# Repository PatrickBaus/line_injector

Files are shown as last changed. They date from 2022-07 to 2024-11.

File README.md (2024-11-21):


# Line Injector
This repository contains the schematics and mechanical files for a line injector.

## Contents
- [Introduction](#introduction)
- [Bode Plot](#bode-plot)
- [PCB Design Files](#pcb-design-files)
- [Mechanical Design Files](#mechanical-design-files)
- [Related Repositories](#related-repositories)
- [Versioning](#versioning)
- [License](#license)

## Introduction
A line injector can be used to inject a ripple voltage into the supply line of a circuit. This can, for example, be used to measure the [power supply rejection ratio (PSRR)](https://en.wikipedia.org/wiki/Power_supply_rejection_ratio) of a regulator.

Key Features:
 * Bandwidth (-3 dB): 6 Hz - 35 MHz (into 50 Ω)
 * Passband transfer function is about 0.95 V/V (@ 5V) and 0.975 V/V (@ 15V)
 * Maximum input voltage: 50 V
 * Maximum current: 5 A
 * Remote sensing inputs to compensate for the voltage drop over the MOSFET

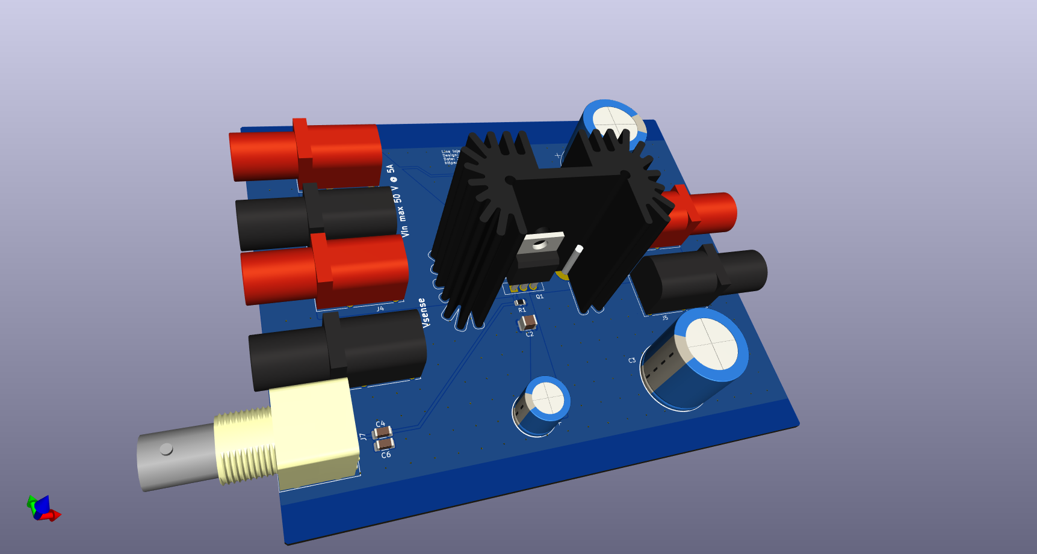
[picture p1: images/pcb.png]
Line injector pcb


The design was done using [KiCAD 8](https://www.kicad.org/).

## Bode Plot
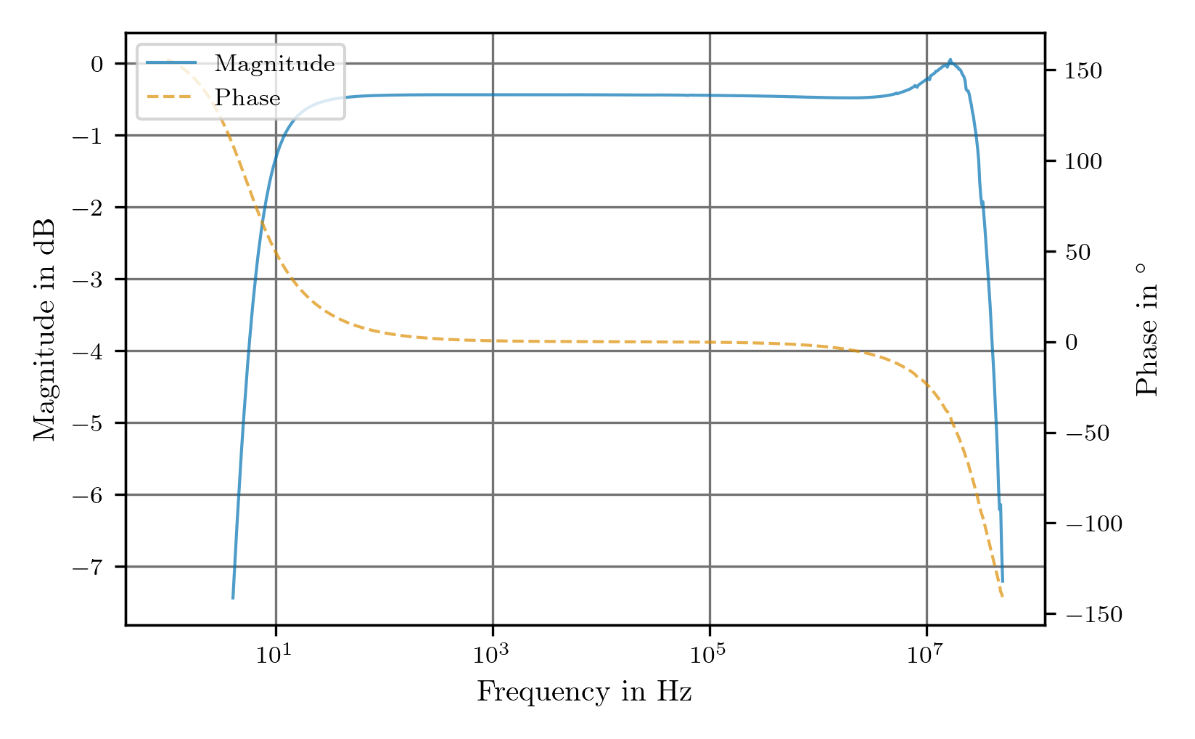
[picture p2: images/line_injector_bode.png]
Bode Plot


Additionally, a report from the Bode 100 VNA used to characterize the injector can be found [here](/supplemental/Line%20Injector_JFW.pdf).

Photos of the finished design
------------------------------

### Front
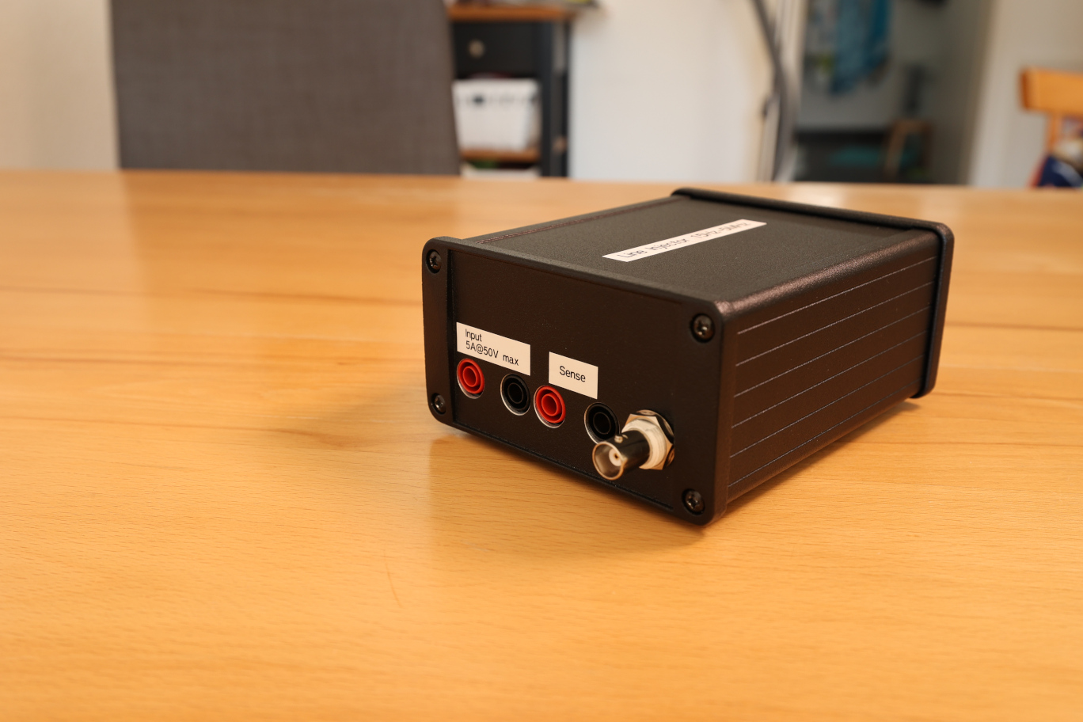
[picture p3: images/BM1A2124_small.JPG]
Line injector photo front


### Back
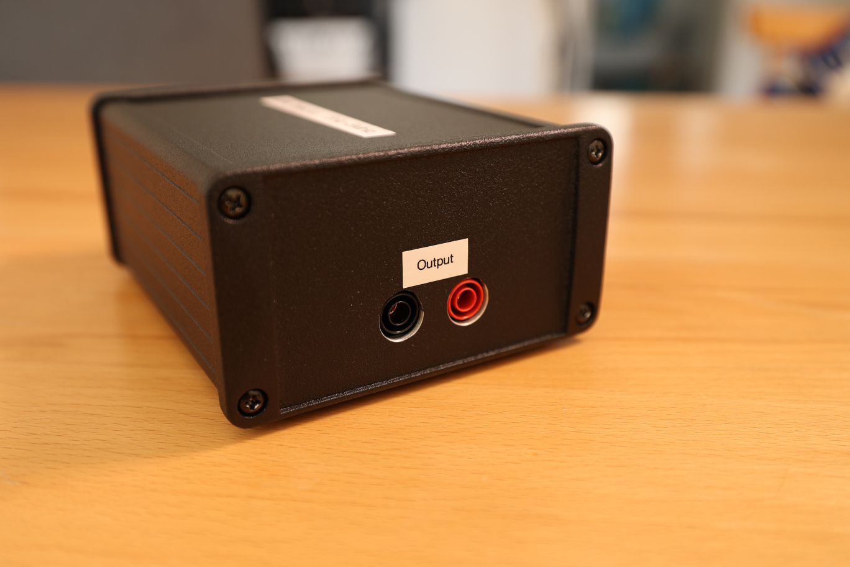
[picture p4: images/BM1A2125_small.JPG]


### PCB
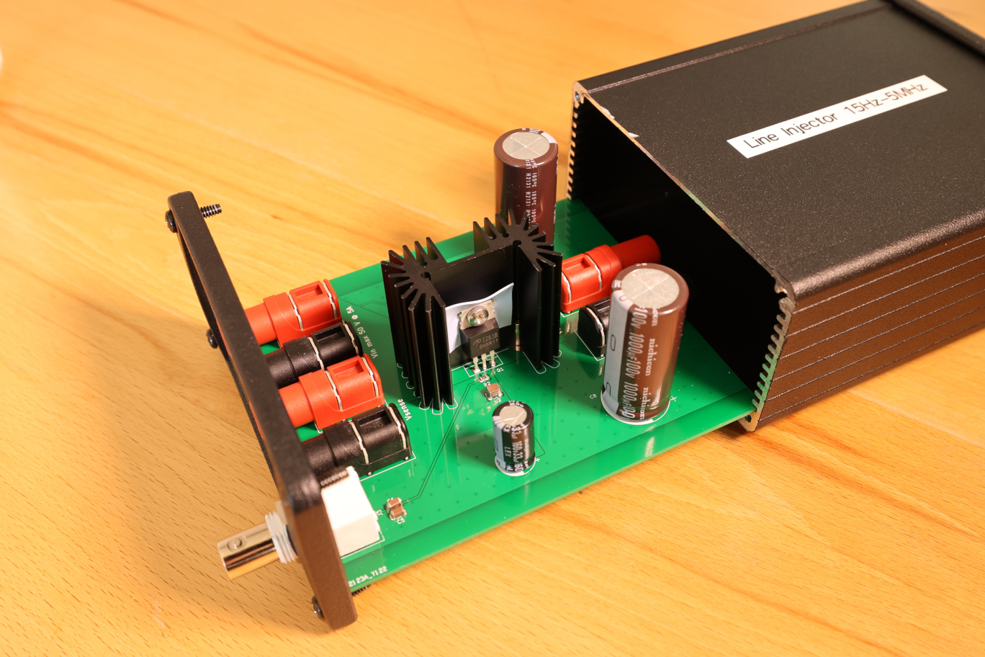
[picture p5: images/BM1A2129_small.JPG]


## PCB Design Files
The root folder contains the KiCAD files. The bill of materials can be found on the [releases](../../releases) page along with Gerber files for production.

## Mechanical Design Files
The PCB fits into a Hammond Manufacturing [1457N1201EBK](https://www.hammfg.com/electronics/small-case/extruded/1457-emi) case. Additionally a few drilled holes need to be drilled for the connectors.

## Related Repositories
See the following repositories for more information.

KiCAD footprints: https://github.com/PatrickBaus/footprints.pretty

## Versioning
I use [SemVer](http://semver.org/) for versioning. For the versions available, see the [tags](../../tags) available for this repository.

- MAJOR versions in this context mean a breaking change to the external interface of the hardware like different connectors or functions.
- MINOR versions contain changes to the hardware that only affect the inner workings of the circuit, but otherwise the performance is unaffected.
- PATCH versions do not affect the schematics or invalidate older bill of materials. These changes may include updated components (to replace obsolete parts for example), an updated silkscreen, or fixed typos.

## License
This work is released under the CERN-OHL-W
See [https://ohwr.org/cern_ohl_w_v2.pdf](https://ohwr.org/cern_ohl_w_v2.pdf) or the included LICENSE file for more information.

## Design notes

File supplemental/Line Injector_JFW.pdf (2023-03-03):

## Measurement: Transmission / Reflection

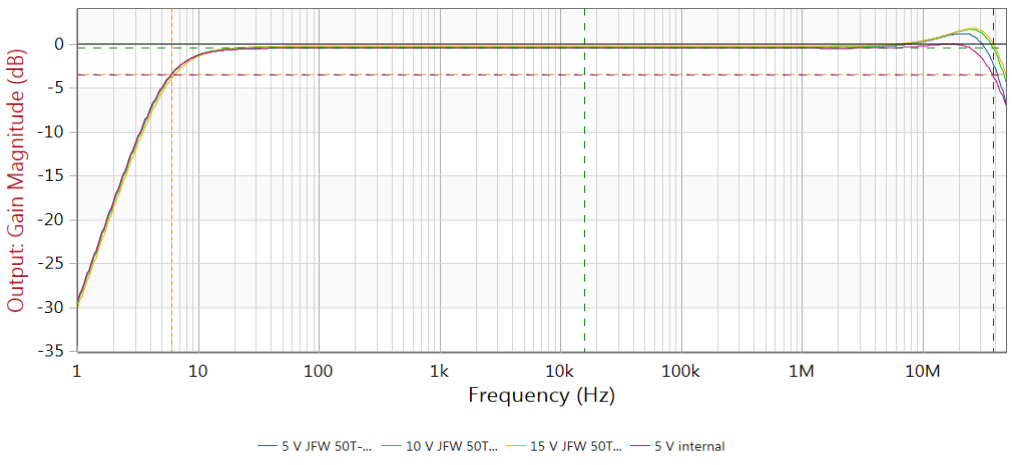
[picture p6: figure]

27.07.2022, 12:16 | Line Injector_JFW.pdf | Page 1/1
Cursor 1 | Cursor 2 | Cursor 3
Frequency | 15,828 kHz | 6,029 Hz | 38,902 MHz
Output | Magnitude (dB) | Magnitude (dB) | | Magnitude (dB)
5 V internal | -437,712 mdB | -3,471 dB | | -3,52 dB
| Delta C2-C1 | Delta C3-C1
Frequency | -15,822 kHz | 38,886 MHz
Output | Magnitude (dB) | Magnitude (dB)
5 V internal | -3,033 dB | -3,083 dB
Sweep | | Calibration | Full-Range | User-Range
Start frequency: | 1 Hz | Gain | Active | -
Stop frequency: | 50 MHz | Impedance | - | -
Center frequency: | 25 MHz
Span: | 50 MHz | Termination | Channel 1 | Channel 2
Sweep mode: | Logarithmic | Gain | 1 MΩ | 50 Ω
Numer of points: | 801 | Impedance | 1 MΩ | 50 Ω
Hardware setup | | Attenuator setting | Channel 1 | Channel 2
Device type: | No device connected! | Transmission | 20 dB | 20 dB
Serial number: | No device connected! | Reflection | 10 dB | 10 dB
Receiver bandwidth: | 30 Hz
Output level: | 0 dBm | Receiver switch | Channel 1 | Channel 2
DUT settling time: | 0 s | Gain | Internal | External
| | Impedance | Internal | Internal

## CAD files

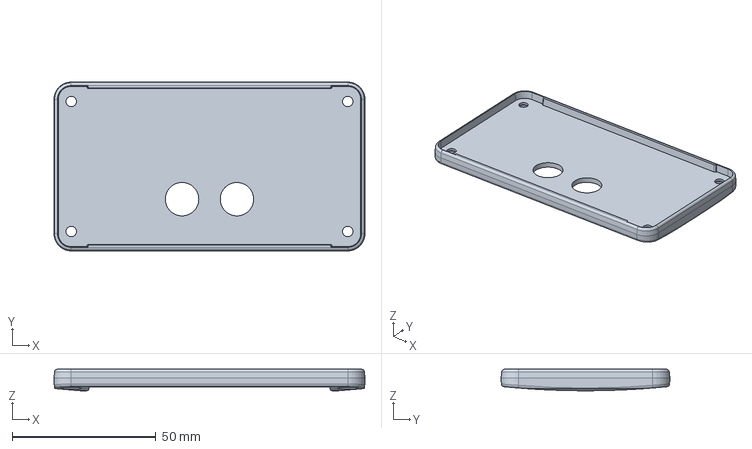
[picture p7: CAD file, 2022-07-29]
mechanical/Backpanel.step
108.0 x 58.6 x 7.50 mm

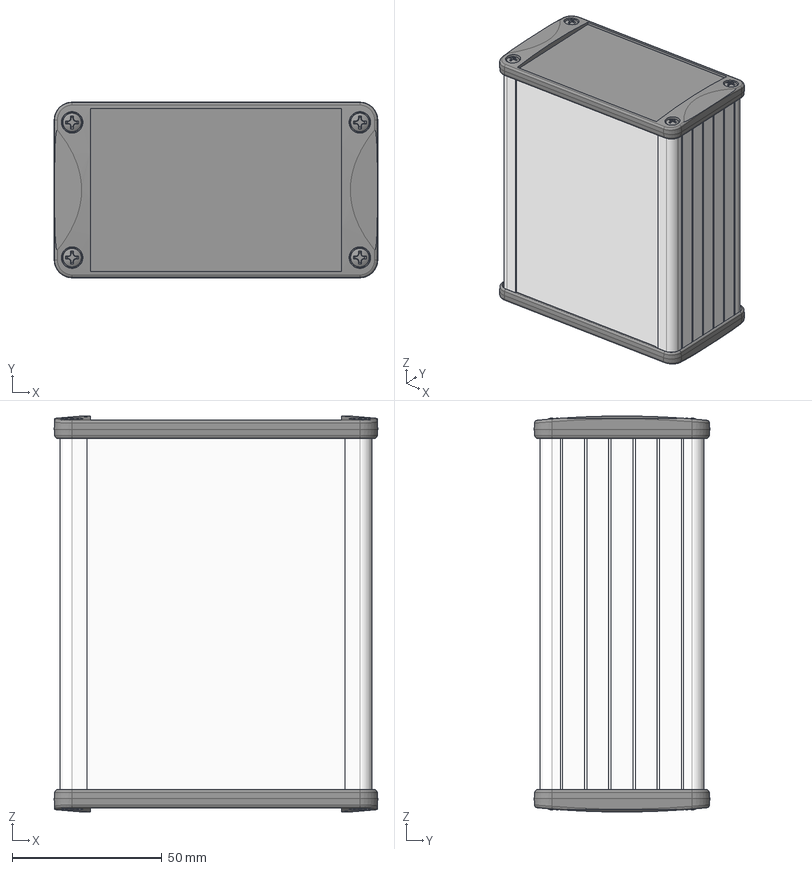
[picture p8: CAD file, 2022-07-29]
mechanical/1457N1201EBK.stp
108.0 x 58.6 x 132.1 mm
100mm Ext
1457N1201 Gasket x 2
100mm End PNL A x 2
90 O-ring x 8
91249A148 x 8

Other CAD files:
mechanical/Frontpanel.step
mechanical/Backpanel.dwg
mechanical/Backpanel.ipt
mechanical/Frontpanel.dwg
mechanical/Frontpanel.ipt

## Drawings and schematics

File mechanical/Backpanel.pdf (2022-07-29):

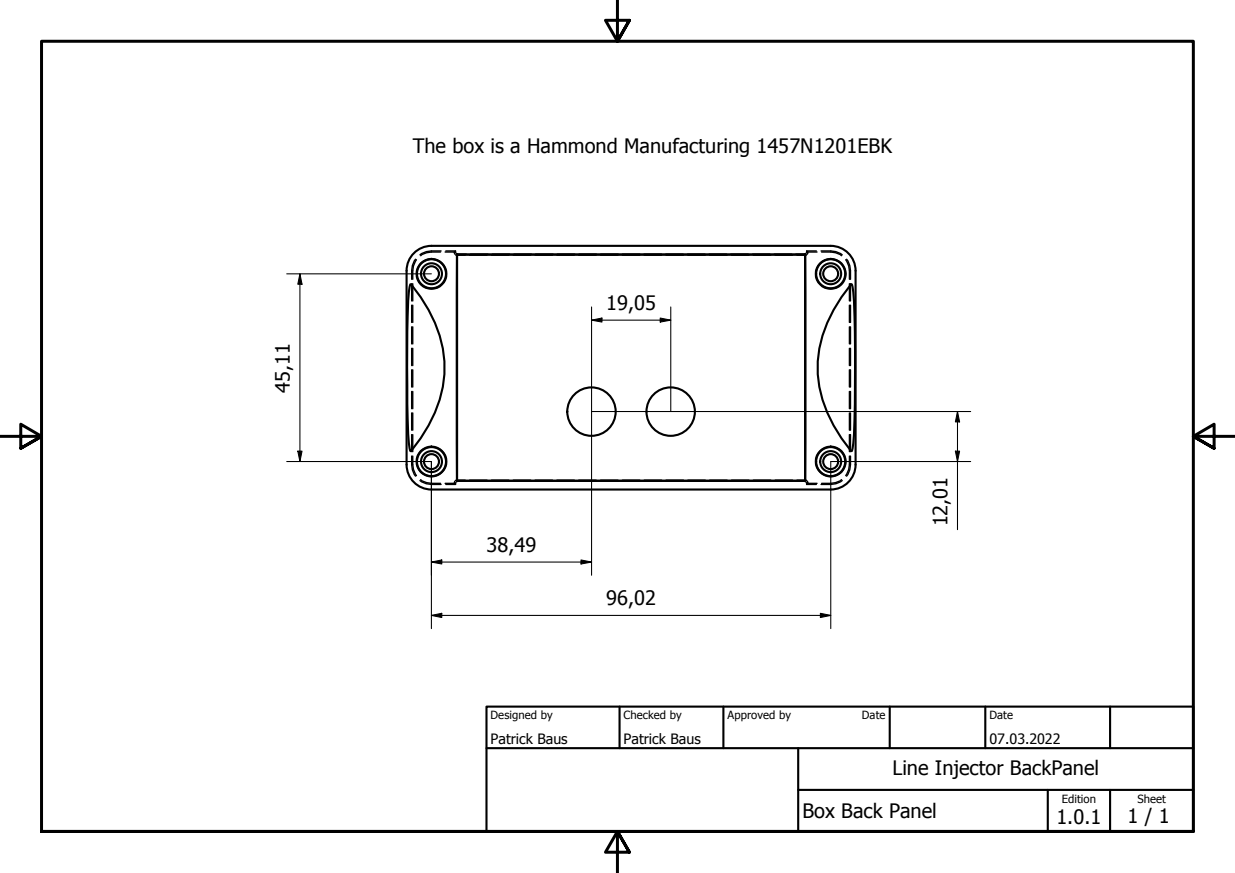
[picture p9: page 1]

The box is a Hammond Manufacturing 1457N1201EBK

Designed by Patrick Baus | Checked by Patrick Baus | Approved by Date | Date 07.03.2022

Line Injector BackPanel

Box Back Panel | Edition 1.0.1 | Sheet 1 / 1

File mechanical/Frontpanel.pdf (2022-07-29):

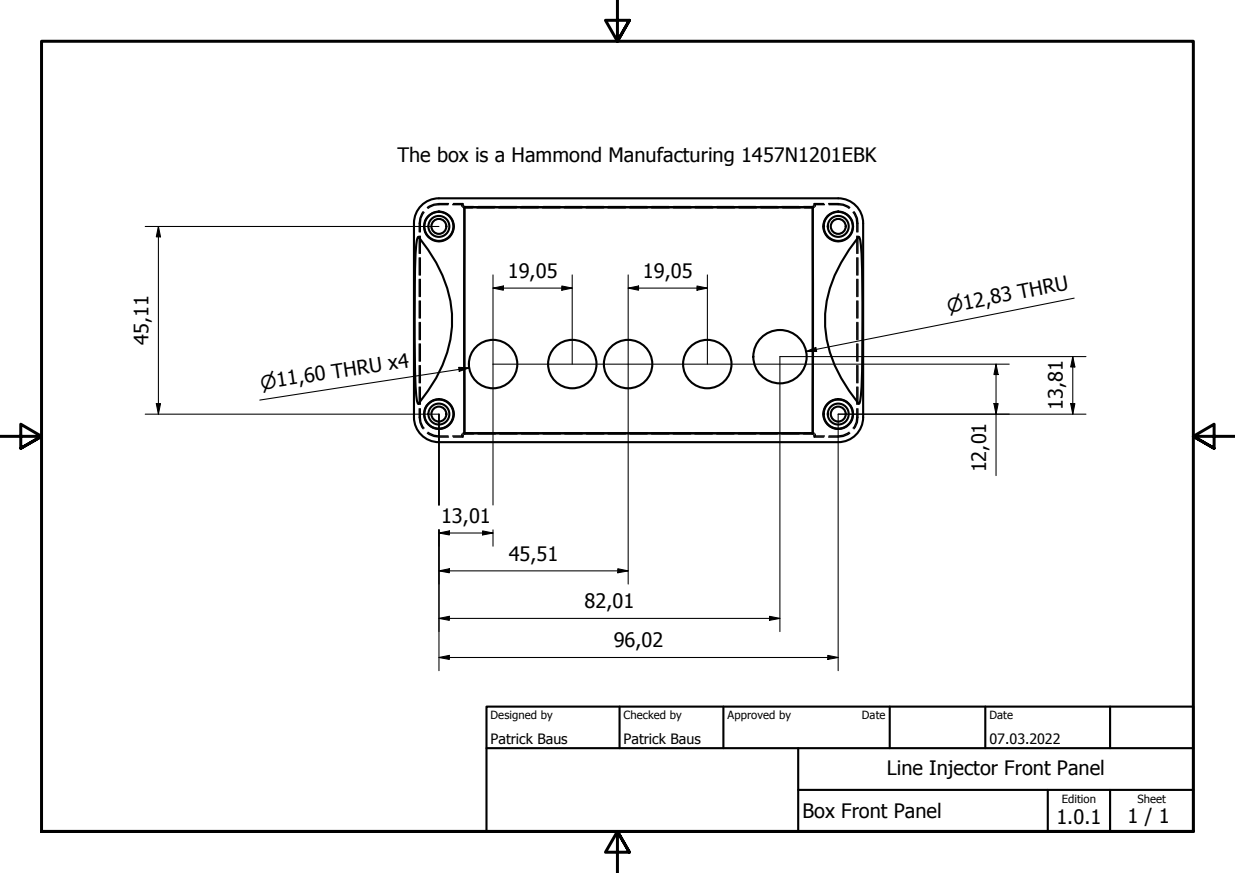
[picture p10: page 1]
⌀11,60 THRU x4; ⌀12,83 THRU

The box is a Hammond Manufacturing 1457N1201EBK

Designed by Patrick Baus | Checked by Patrick Baus | Approved by Date | Date 07.03.2022

Line Injector Front Panel

Box Front Panel | Edition 1.0.1 | Sheet 1 / 1

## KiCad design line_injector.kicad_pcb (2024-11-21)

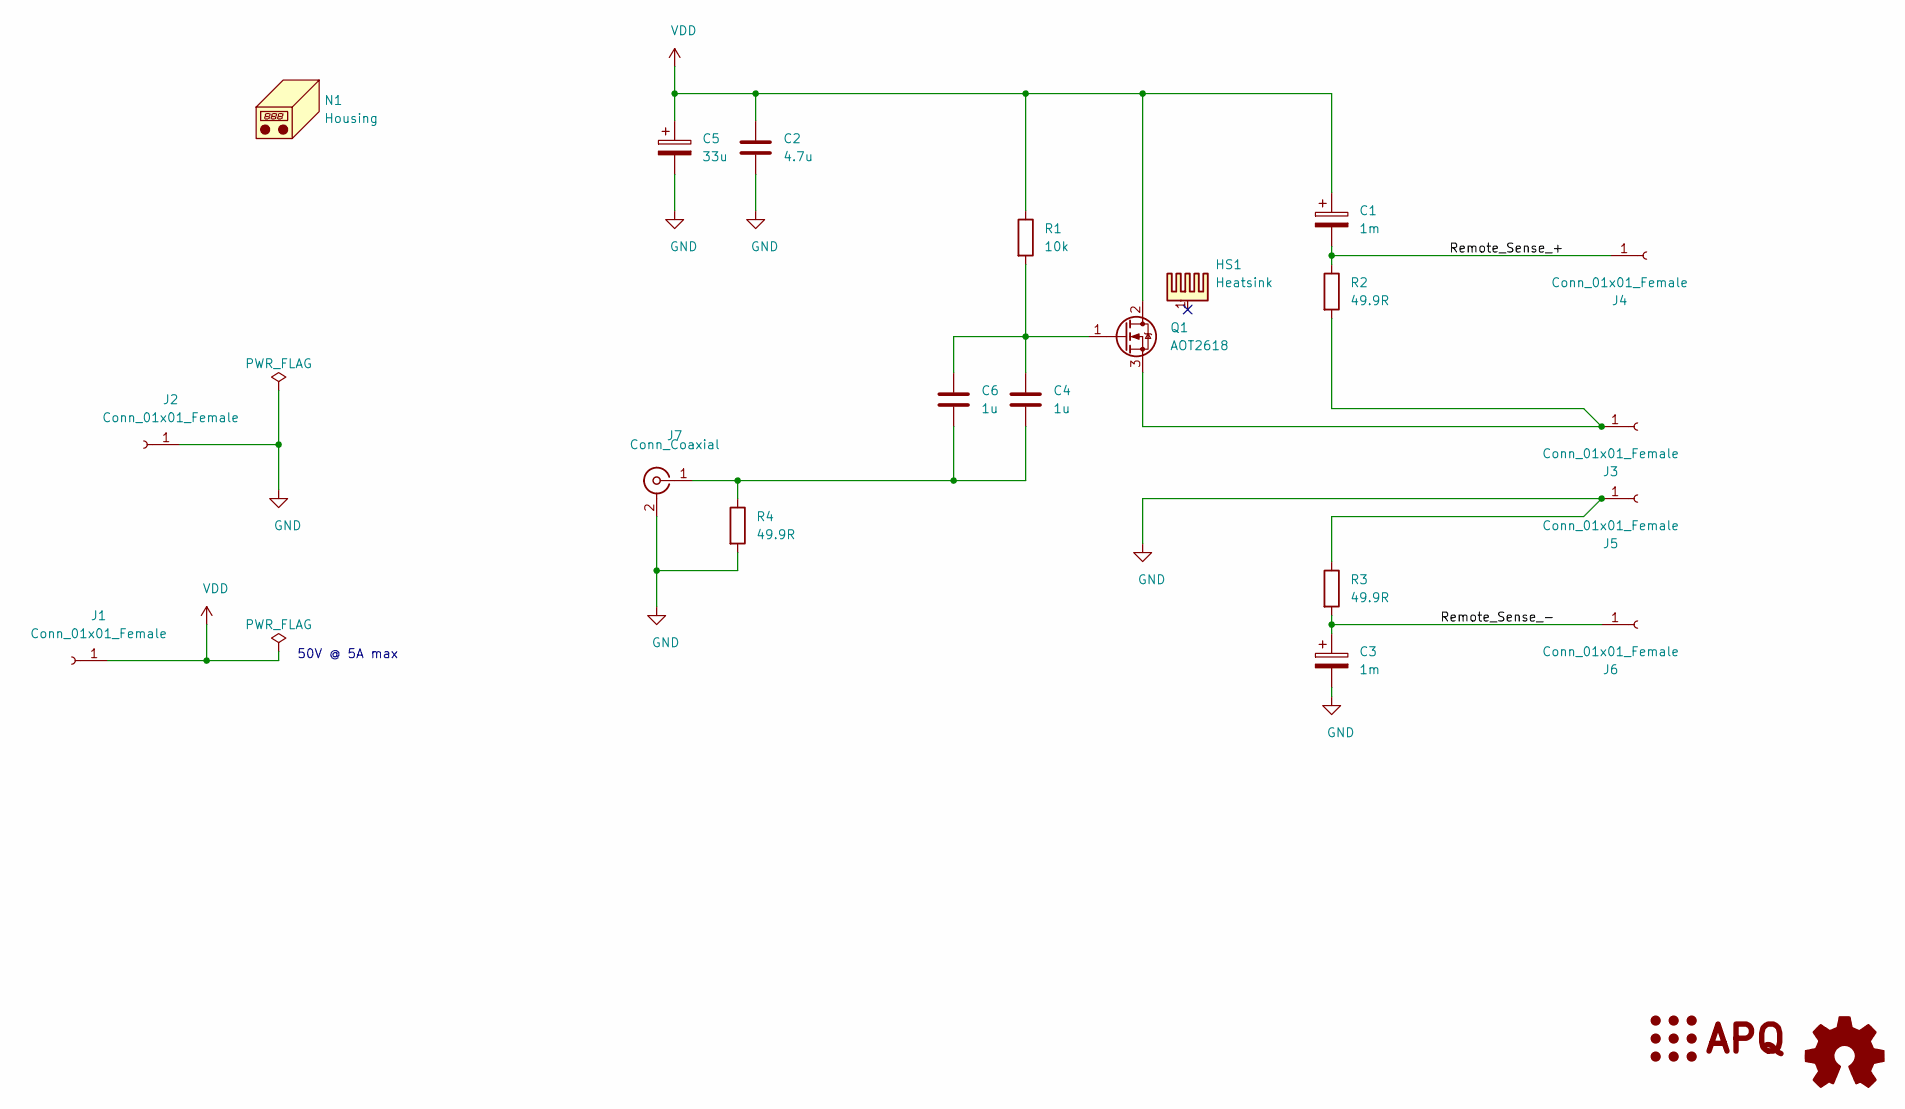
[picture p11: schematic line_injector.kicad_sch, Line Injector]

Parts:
C1, C3: 1m; CP_Radial_D18.0mm_P7.50mm
C2: 4.7u; C_1210_3225Metric
C4, C6: 1u; C_1206_3216Metric
C5: 33u; CP_Radial_D10.0mm_P5.00mm
HS1: Heatsink; Heatsink_42x25mm_2xFixation_Ohmite-R-series
J1, J3, J4: Conn_01x01_Female; Banana_Cliff_FCR7350R_S16N-PC_Horizontal
J2, J5, J6: Conn_01x01_Female; Banana_Cliff_FCR7350B_S16N-PC_Horizontal
J7: Conn_Coaxial; BNC_Amphenol_B6252HB-NPP3G-50_Horizontal
LOGO1: Logo_APQ; APQ-Logo_small
LOGO2: Logo_Open_Hardware_Small; OSHW-Logo_7.5x8mm_SilkScreen
N1: Housing
Q1: AOT2618; TO-220-3_Vertical
R1: 10k; R_0805_2012Metric
R2, R3, R4: 49.9R; R_1206_3216Metric

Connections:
/Remote_Sense_+: C1.2, J4.1, R2.1
/Remote_Sense_-: C3.1, J6.1, R3.2
GND: C2.2, C3.2, C5.2, J2.1, J5.1, J7.2 (Ext), R3.1, R4.2
unnamed: J3.1, Q1.3 (S), R2.2
unnamed: C4.2, C6.2, J7.1 (In), R4.1
unnamed: C4.1, C6.1, Q1.1 (G), R1.2
VDD: C1.1, C2.1, C5.1, J1.1, Q1.2 (D), R1.1

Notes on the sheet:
50V @ 5A max

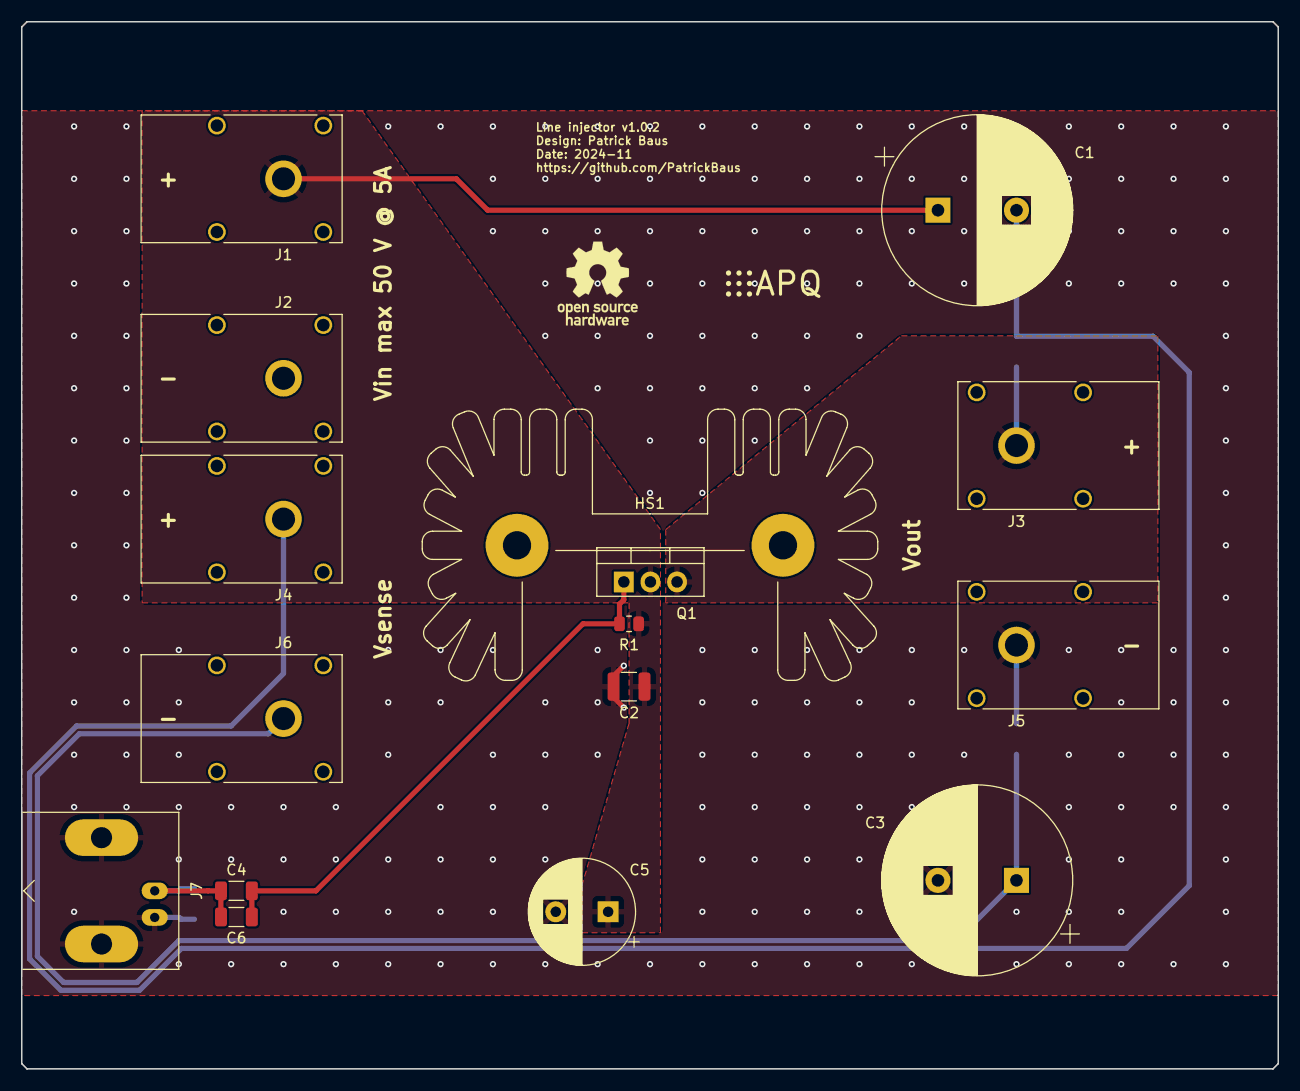
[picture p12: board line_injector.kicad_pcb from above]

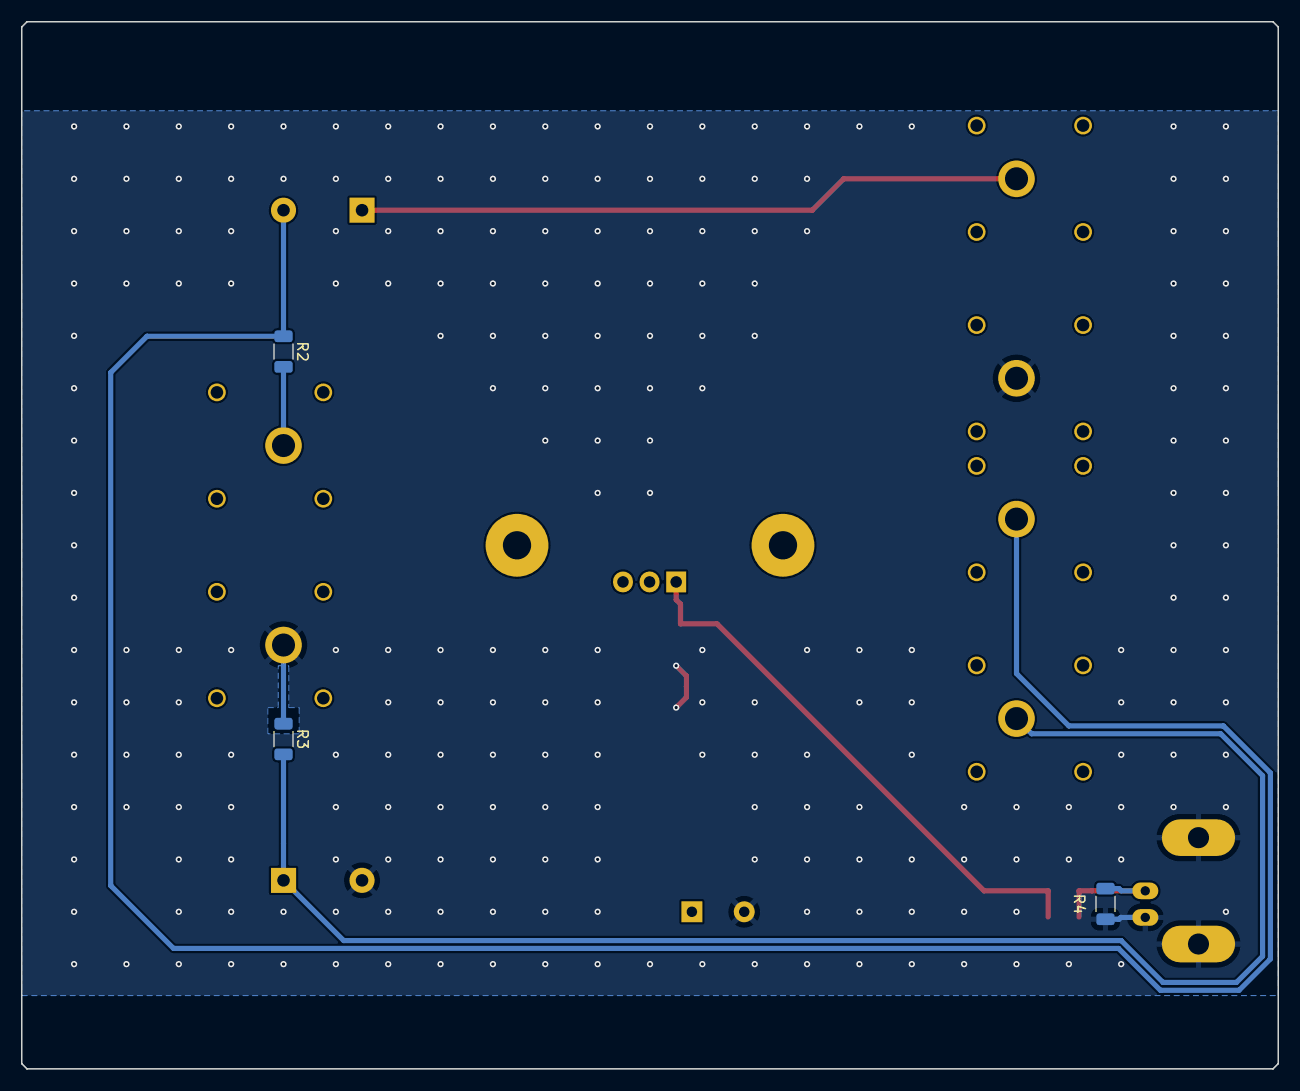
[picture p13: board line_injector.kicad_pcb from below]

Board: 2 copper layers, 120.0 x 100.0 mm, 21 parts (3 on the bottom side), 7 nets.

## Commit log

2022-07-29 Added BOM
    [bom_v1.0.1.csv, main.kicad_pcb, main.kicad_sch]
2022-07-29 Updated footprints
    [main.kicad_pcb]
2024-11-21 Update to KiCad 8 (#1)
    [main.kicad_pcb, main.kicad_sch]
2024-11-21 Updated libs (#2)
    [main.kicad_pcb, main.kicad_sch]
2024-11-21 Renamed project files from main.* to line_injector.* (#3)
    [line_injector.kicad_pcb, line_injector.kicad_sch]
2024-11-21 Add CI workflow (#4)
    * Add CI workflow
    * Remove BOM from git
    [bom_v1.0.1.csv]
2024-11-21 Udpated license to CERN-OHL-W (#5)
    [line_injector.kicad_pcb, line_injector.kicad_sch]
2024-11-21 Bump version to 1.0.2
    [line_injector.kicad_pcb, line_injector.kicad_sch]
2024-11-21 Added RoHS info (#7)
    Added temperature data
    [line_injector.kicad_pcb, line_injector.kicad_sch]
2025-11-26 Bump libraries from `80d58ef` to `ba5563d` (#8)
    Bumps [libraries](https://github.com/PatrickBaus/KiCad-libraries) from `80d58ef` to `ba5563d`.
    - [Commits](https://github.com/PatrickBaus/KiCad-libraries/compare/80d58efa29fc28aa49b090516bd5b7168ac740c8...ba5563d66c23dea06d561adcb039ddac5a03efdf)
    ---
    updated-dependencies:
    - dependency-name: libraries
    dependency-version: ba5563d66c23dea06d561adcb039ddac5a03efdf
    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
2025-12-17 Bump libraries from `ba5563d` to `d79317d` (#9)
    Bumps [libraries](https://github.com/PatrickBaus/KiCad-libraries) from `ba5563d` to `d79317d`.
    - [Commits](https://github.com/PatrickBaus/KiCad-libraries/compare/ba5563d66c23dea06d561adcb039ddac5a03efdf...d79317d926704a58090a36fac06bfafa731a048b)
    dependency-version: d79317d926704a58090a36fac06bfafa731a048b
    dependency-type: direct:production
    ...
    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
2026-02-09 Bump libraries from `d79317d` to `4179135` (#10)
    Bumps [libraries](https://github.com/PatrickBaus/KiCad-libraries) from `d79317d` to `4179135`.
    - [Commits](https://github.com/PatrickBaus/KiCad-libraries/compare/d79317d926704a58090a36fac06bfafa731a048b...41791358010d2de5d2401e25bd30de257630acf6)
    dependency-version: 41791358010d2de5d2401e25bd30de257630acf6
    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
2026-10-01 Bump libraries from `4179135` to `e738e27` (#15)
    Bumps [libraries](https://github.com/PatrickBaus/KiCad-libraries) from `4179135` to `e738e27`.
    - [Commits](https://github.com/PatrickBaus/KiCad-libraries/compare/41791358010d2de5d2401e25bd30de257630acf6...e738e270946db822ff06ec80e54fb3b10e246ee1)
    dependency-version: e738e270946db822ff06ec80e54fb3b10e246ee1
    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

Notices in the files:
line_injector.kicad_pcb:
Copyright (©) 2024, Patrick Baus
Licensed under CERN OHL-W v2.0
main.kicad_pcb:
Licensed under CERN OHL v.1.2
